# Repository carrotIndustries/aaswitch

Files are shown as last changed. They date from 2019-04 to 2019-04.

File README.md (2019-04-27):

The audio activated switch is a device that switches power to an audio 
amplifier based on the presence of a line level audio signal.

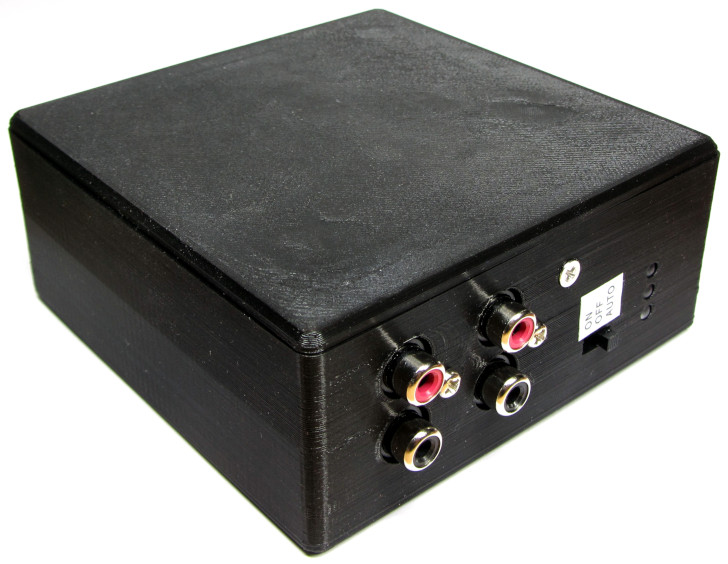
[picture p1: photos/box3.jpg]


[More pictures](photos/)

# Motivation

My audio amplifier from the 1980s consumes about 30 W of power no 
matter if there's an input signal or it's just sitting there doing 
nothing. Manually turning it on if needed wouldn't have been practical 
since it's too hard to reach below the desk and I'm lazy.

# Implementation

An MCU (ATtiny 85) listens to the line level audio signal using it's 
builtin ADC and turns on a solid-state relay if the peak-to-peak 
detector implemented in firmware reports signal presence for a 
certain time (less than one second). The relay is turned off after 
about 5 minutes of uninterrupted silence.

# Construction

Apart from achieving the desired (pretty trivial) functionality,  this 
project's goal was a to gain experience in the integration of board 
design and mechanical design as it's standard in the industry. One 
aspect of this is eliminating wired connections, so all connectors are 
directly mounted to the board. Indicators use SMD LEDs and light pipes 
instead of flange-mounting regular through hole LEDs.

As we can see from the photo below, that goal has been achieved. The 
case has been 3D printed on a FlashForge Creator Pro using PLA 
filament.

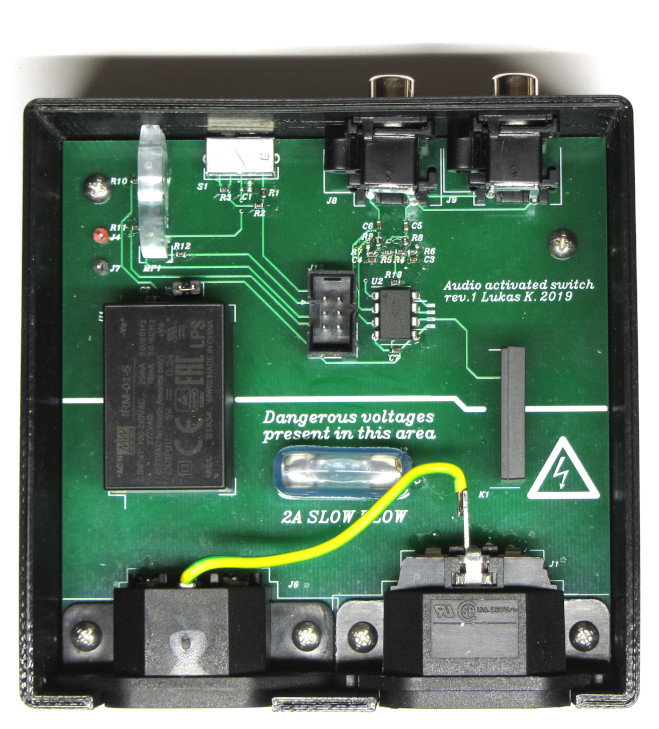
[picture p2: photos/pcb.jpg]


Comparing this to a project of mine from 8 years ago, the progress 
should be pretty clear:

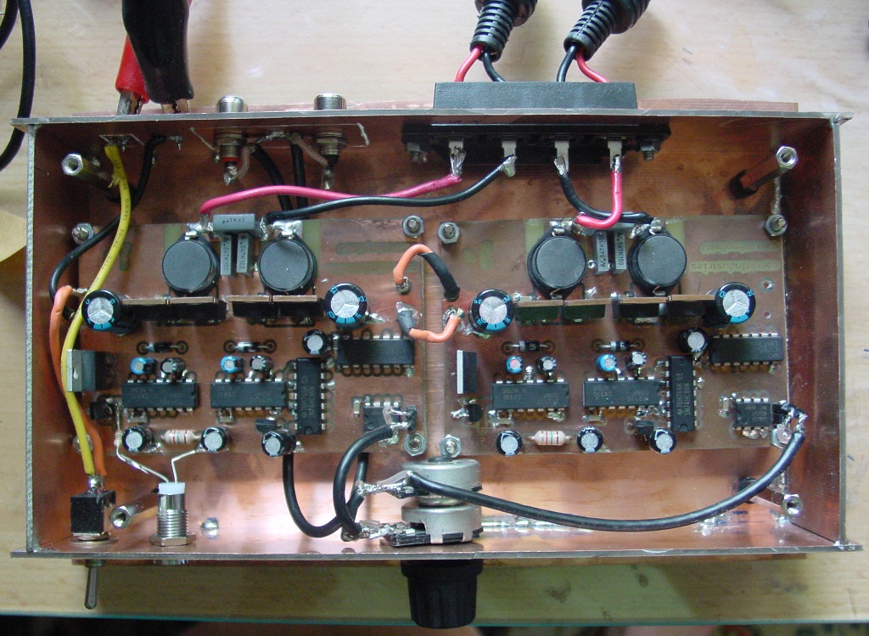
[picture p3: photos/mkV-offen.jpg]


# CAD

Board design has been done in horzion EDA. 

Mechanical design has been done in FreeCAD 0.18. Due to licensing 
restrictions, the vendor-supplied 3D models aren't included. As this is 
one of my first projects involving mechanical CAD, the model isn't as 
robust as it should be.

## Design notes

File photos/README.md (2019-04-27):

People like photos, so I took some.

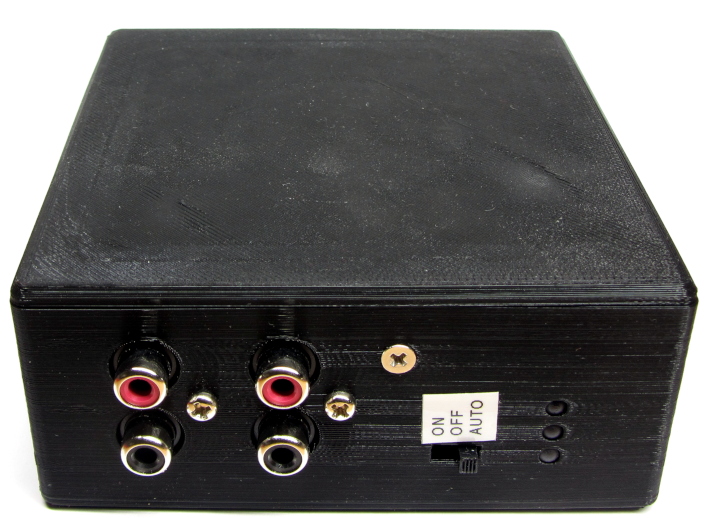
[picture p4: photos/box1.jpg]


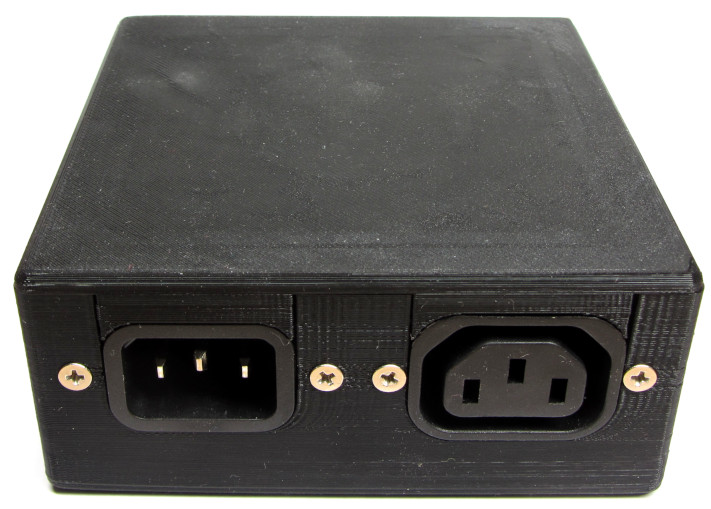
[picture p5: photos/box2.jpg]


box

box

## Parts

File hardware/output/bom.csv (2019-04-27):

QTY | MPN | Value | Manufacturer | Ref. Des.
1 | ATtinyx5 SOIC | ATtinyx5 SOIC | Microchip | U3
1 | PX0675/PC | PX0675/PC | Bulgin | J1
1 | EG2315A | EG2315A | E-Switch | S1
1 | 5000 | 5000 | Keystone | J4
1 | G3MC-202P-VD-1 DC5 | G3MC-202P-VD-1 DC5 | Omron | K1
1 | 7511B11 | 7511B11 | VCC | MP1
1 | ATtinyx5 DIP | ATtinyx5 DIP | Microchip | U2
1 | PX0580/PC | PX0580/PC | Bulgin | J6
1 | CPL-CAP-X5R-0805-10UF-16V | 10 µF | CPL | C2
1 | IRM-01-5 | IRM-01-5 | Mean Well | U1
1 | Generic Pin header 1×2, 2.54mm pitch, vertical | Generic Pin header 1×2, 2.54mm pitch, vertical |  | J5
1 | Generic IDC header 2×3, 2.54mm pitch, vertical | Generic IDC header 2×3, 2.54mm pitch, vertical |  | J10
1 | 5001 | 5001 | Keystone | J7
2 | 3517 | 3517 | Keystone | J2, J3
2 | RCJ-2221 | RCJ-2221 | CUI | J8, J9
2 | CPL-RES-0603-1K-0.1W | 1 kΩ | CPL | R6, R7
3 | 150060GS75000 | 150060GS75000 | Würth Elektronik | D1, D2, D3
6 | CPL-CAP-X7R-0603-100NF-50V | 100 nF | CPL | C1, C3, C4, C5, C6, C7
11 | CPL-RES-0603-10K-0.1W | 10 kΩ | CPL | R1, R2, R3, R4, R5, R8, R9, R10, R11, R12, R13

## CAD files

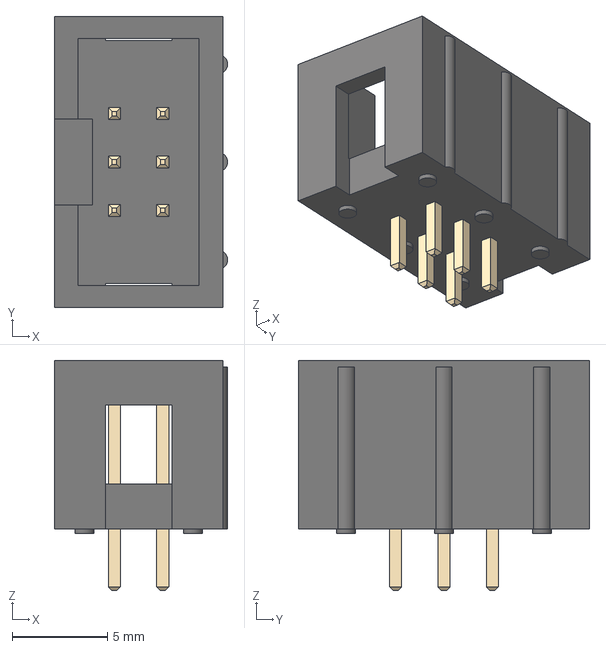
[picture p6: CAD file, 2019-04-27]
hardware/cache/3d_models/pool_6d752bc3-29b3-45df-8cf2-1e3aacefbcc6/3d_models/connector/header-idc/2.54mm/IDC-Header_2x03_P2.54mm_Vertical.step
9.10 x 15.3 x 12.1 mm

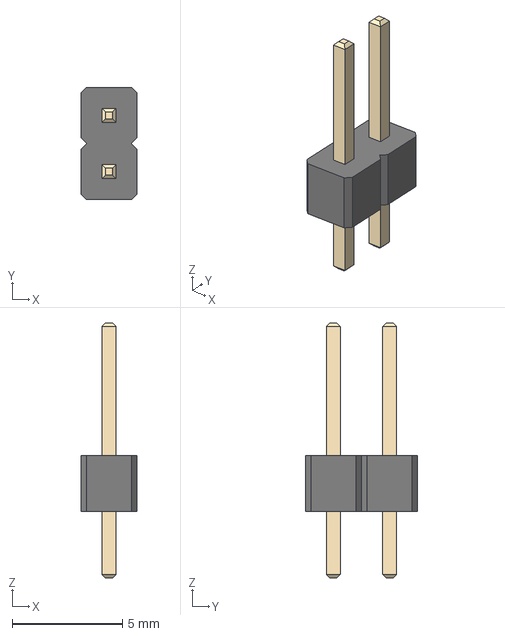
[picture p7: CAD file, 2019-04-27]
hardware/cache/3d_models/pool_6d752bc3-29b3-45df-8cf2-1e3aacefbcc6/3d_models/connector/header/2.54mm/PinHeader_1x02_P2.54mm_Vertical.step
2.54 x 5.08 x 11.5 mm

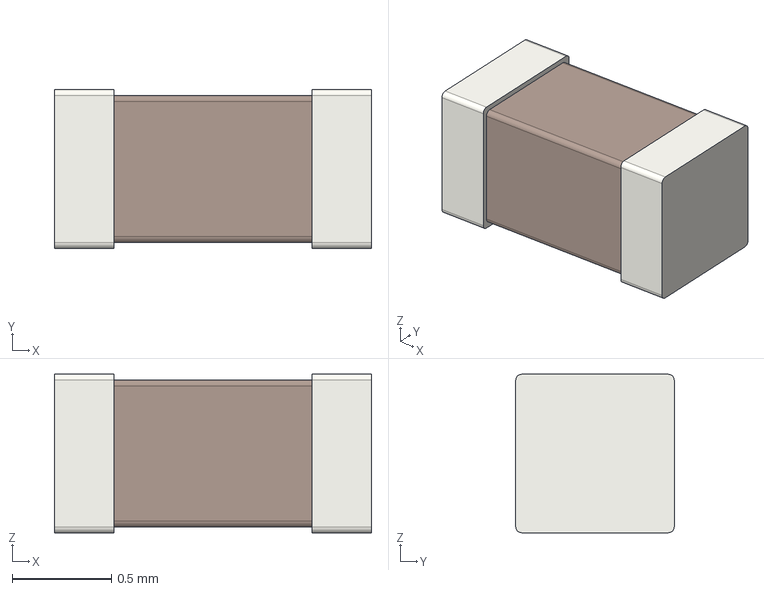
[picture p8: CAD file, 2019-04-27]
hardware/cache/3d_models/pool_6d752bc3-29b3-45df-8cf2-1e3aacefbcc6/3d_models/passive/capacitor/C_0603_1608Metric.step
1.60 x 0.8 x 0.8 mm

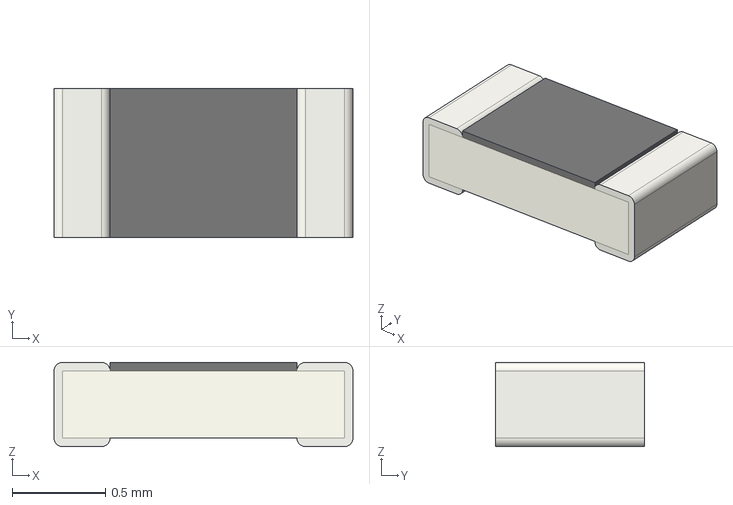
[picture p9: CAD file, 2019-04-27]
hardware/cache/3d_models/pool_6d752bc3-29b3-45df-8cf2-1e3aacefbcc6/3d_models/passive/resistor/R_0603_1608Metric.step
1.60 x 0.8 x 0.45 mm

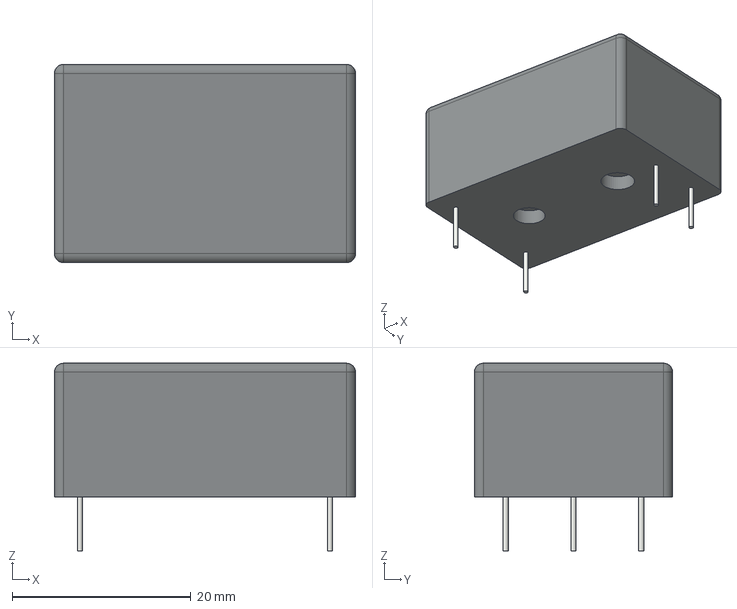
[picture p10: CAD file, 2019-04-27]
hardware/cache/3d_models/pool_6d752bc3-29b3-45df-8cf2-1e3aacefbcc6/3d_models/psu/irm-01.step
33.7 x 22.2 x 21.0 mm

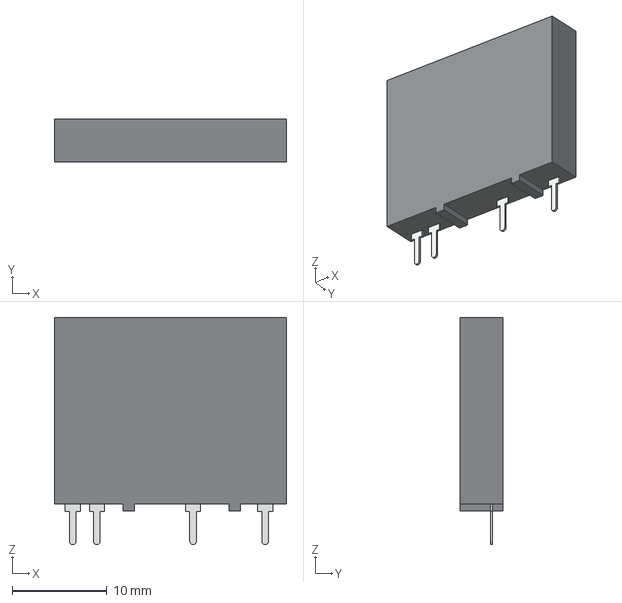
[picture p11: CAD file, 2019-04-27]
hardware/cache/3d_models/pool_6d752bc3-29b3-45df-8cf2-1e3aacefbcc6/3d_models/relay/solid-state/g3mc.step
24.5 x 4.50 x 24.0 mm

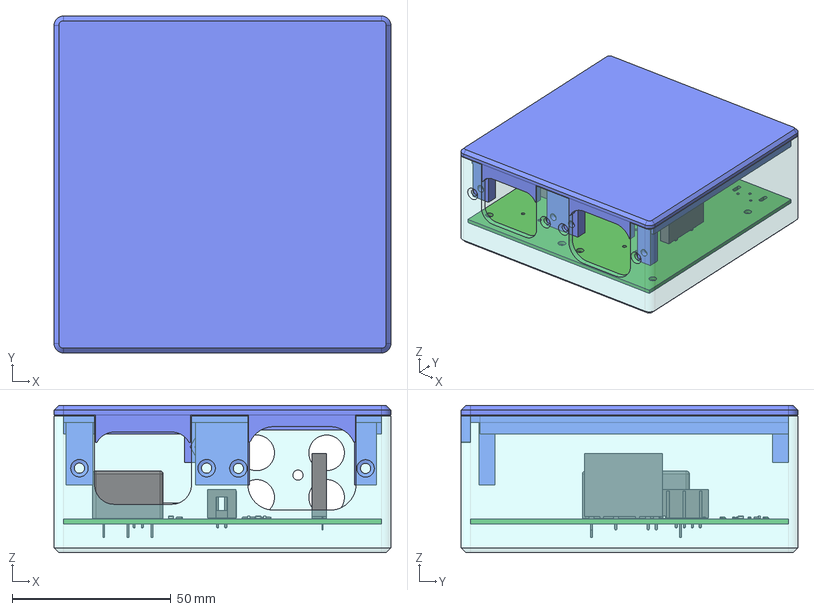
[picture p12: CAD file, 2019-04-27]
mech/aaswitch.FCStd
106.0 x 106.0 x 46.2 mm

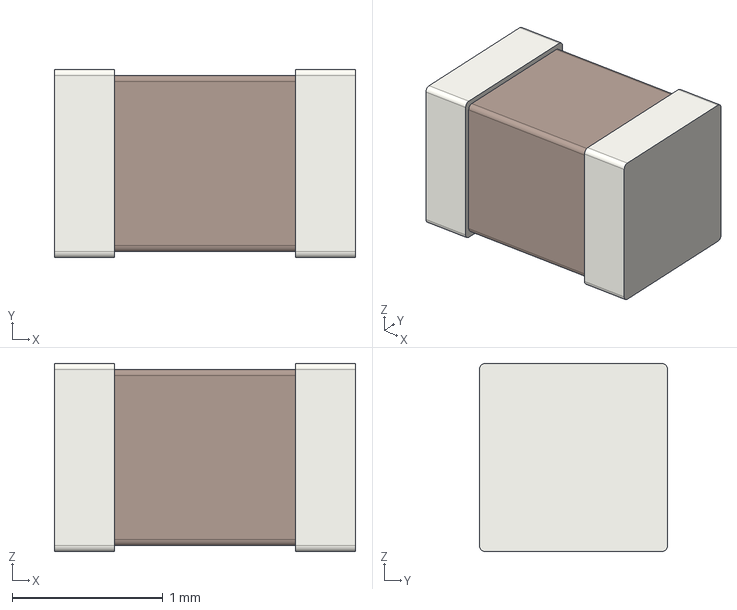
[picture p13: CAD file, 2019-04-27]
hardware/cache/3d_models/pool_6d752bc3-29b3-45df-8cf2-1e3aacefbcc6/3d_models/passive/capacitor/C_0805_2012Metric.step
2.00 x 1.25 x 1.25 mm

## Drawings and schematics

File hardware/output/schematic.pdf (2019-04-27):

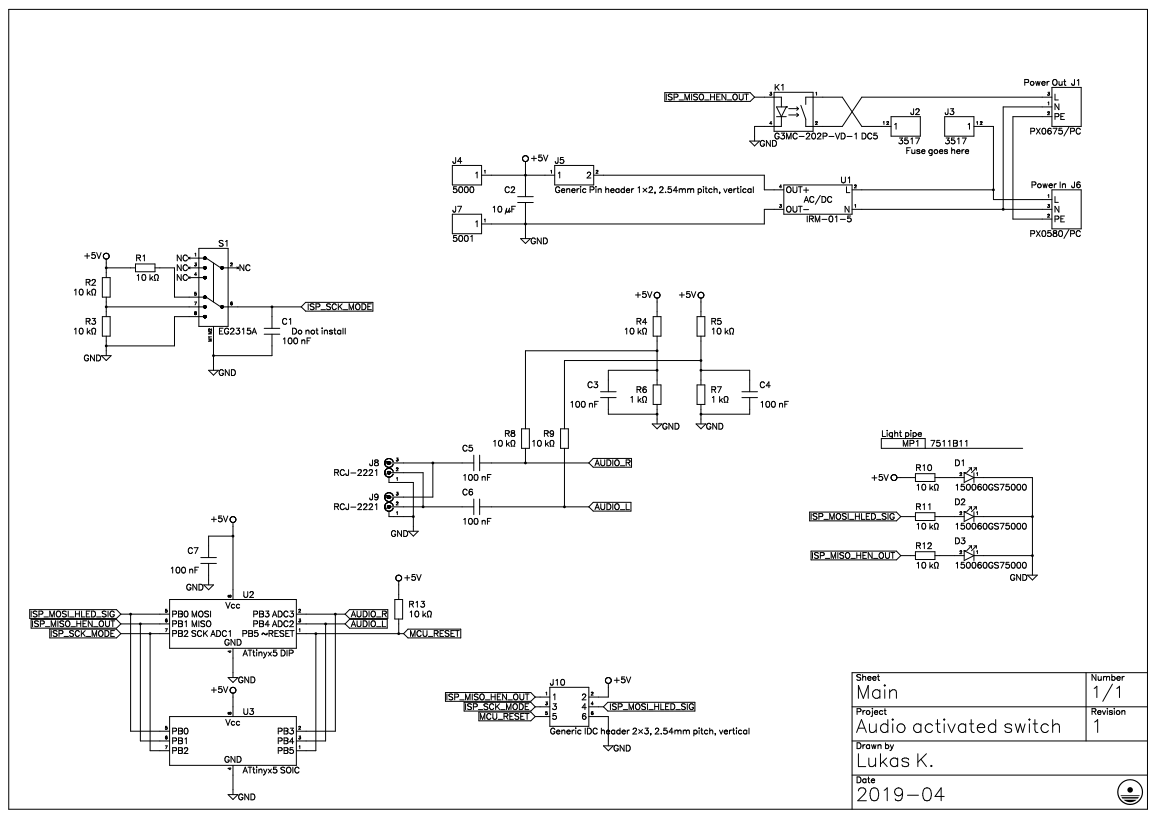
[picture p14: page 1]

Drawn by Lukas K.

Date

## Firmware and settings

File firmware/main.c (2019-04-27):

#include <avr/io.h>
#include <avr/interrupt.h>
#define F_CPU 1000000
#include <util/delay.h>
#include <stdint.h>
#include <avr/eeprom.h>

//extern const __flash uint8_t gammatab[256];

#define ABS(a) (((a) < 0) ? -(a) : (a))

#define KEEP_PRELOAD 1000

const uint8_t dimtab[] = {255, 127, 64, 4};

void out_init() {
	DDRB |= (1<<PB0) | (1<<PB1);
}

void out_set(uint8_t x) {
	if(x)
		PORTB |= (1<<PB1);
	else
		PORTB &= ~(1<<PB1);
}

void led_sig_set(uint8_t x) {
	if(x)
		PORTB |= (1<<PB0);
	else
		PORTB &= ~(1<<PB0);
}

typedef enum {
	M_AUTO,
	M_ON,
	M_OFF
} mode_t;

void inc_clamp(uint16_t *x) {
	if(*x < 0xfffe)
		(*x)++;
}

int main(void) {
	out_init();
	out_set(1);
	ADMUX = 3 | (1<<REFS1);
	ADCSRA |= (1<<ADEN) | (1<<ADPS0);
	uint16_t prescaler = 1;
	uint16_t amin[2] = {0xffff};
	uint16_t amax[2] = {0xffff};
	uint8_t ch = 0;
	uint8_t mode = M_ON;
	uint16_t counter_on = 0;
	uint16_t counter_off = 0;
	
	while(1) {
		if(ch == 0) {
			ADMUX = 3 | (1<<REFS1);
		}
		else {
			ADMUX = 2 | (1<<REFS1);
		}
		
		ADCSRA |= (1<<ADSC);
		while(ADCSRA & (1<<ADSC));
		int16_t result = ADCW;
		if(amax[ch] == 0xffff || amin[ch] == 0xffff) {
			amin[ch] = result;
			amax[ch] = result;
		}
		else {
			if(result < amin[ch])
				amin[ch] = result;
			if(result > amax[ch])
				amax[ch] = result;
		}
			
		prescaler--;
		if(prescaler == 0) {
			uint8_t sig = ((amax[0] - amin[0]) > 20) || ((amax[1] - amin[1]) > 20);
			if(sig) {
				inc_clamp(&counter_on);
				counter_off = 0;
			}
			else {
				inc_clamp(&counter_off);
				counter_on = 0;
			}
			led_sig_set(sig);
			switch(mode) {
				case M_ON:
					out_set(1);
				break;
				
				case M_OFF:
					out_set(0);
				break;
				
				case M_AUTO:
					if(counter_on > 5) {
						out_set(1);
					}
					else if(counter_off > 3750) {
						out_set(0);
					}
				
					
				break;
				
			}
			prescaler = 1024;
			amin[0] = 0xffff;
			amin[1] = 0xffff;
			amax[0] = 0xffff;
			amax[1] = 0xffff;
			
			ADMUX = 1;
			
			//dummy conversion
			ADCSRA |= (1<<ADSC);
			while(ADCSRA & (1<<ADSC));
			
			ADCSRA |= (1<<ADSC);
			while(ADCSRA & (1<<ADSC));
			
			uint16_t r = ADCW;
			if(r > 682) {
				mode = M_ON;
			}
			else if(r > 341) {
				mode = M_OFF;
			}
			else {
				mode = M_AUTO;
			}
			
			//dummy conversion
			ADMUX = (1<<REFS1);
			ADCSRA |= (1<<ADSC);
			while(ADCSRA & (1<<ADSC));
			
		}
		ch = !ch;
		
	}
	return 0;
}

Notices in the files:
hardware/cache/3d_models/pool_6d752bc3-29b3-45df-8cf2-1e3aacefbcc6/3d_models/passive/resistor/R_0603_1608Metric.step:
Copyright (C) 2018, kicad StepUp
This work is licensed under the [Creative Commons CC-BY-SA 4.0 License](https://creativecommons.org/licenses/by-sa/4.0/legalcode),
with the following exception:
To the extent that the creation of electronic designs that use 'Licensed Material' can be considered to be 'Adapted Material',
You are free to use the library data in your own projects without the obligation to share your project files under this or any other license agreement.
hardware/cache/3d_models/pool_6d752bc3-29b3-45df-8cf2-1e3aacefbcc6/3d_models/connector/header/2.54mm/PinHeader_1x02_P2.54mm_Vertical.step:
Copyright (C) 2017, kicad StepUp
